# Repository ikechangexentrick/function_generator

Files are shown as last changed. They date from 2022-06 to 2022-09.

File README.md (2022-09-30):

# function_generator
8 channel clock processor/low frequency oscillator

front view

### [Schematic](https://raw.githubusercontent.com/ikechangexentrick/function_generator/master/hw/function_generator_v1_schematic.pdf)

## Prerequisites

### Hardware
- Raspberry Pi Pico
- SSD1306 based OLED display
  - I use [0.96in 128x64 OLED display](https://akizukidenshi.com/catalog/g/gP-12031/)
- MCP4922 Digital-to-Analog converter

### Software (Arduino libraries)
- [Display_OLED](https://github.com/ikechangexentrick/Display_OLED)
  - (required libraries also)
- [AD_DA_Converters](https://github.com/ikechangexentrick/AD_DA_Converters)

## Build instruction

... to be written ...

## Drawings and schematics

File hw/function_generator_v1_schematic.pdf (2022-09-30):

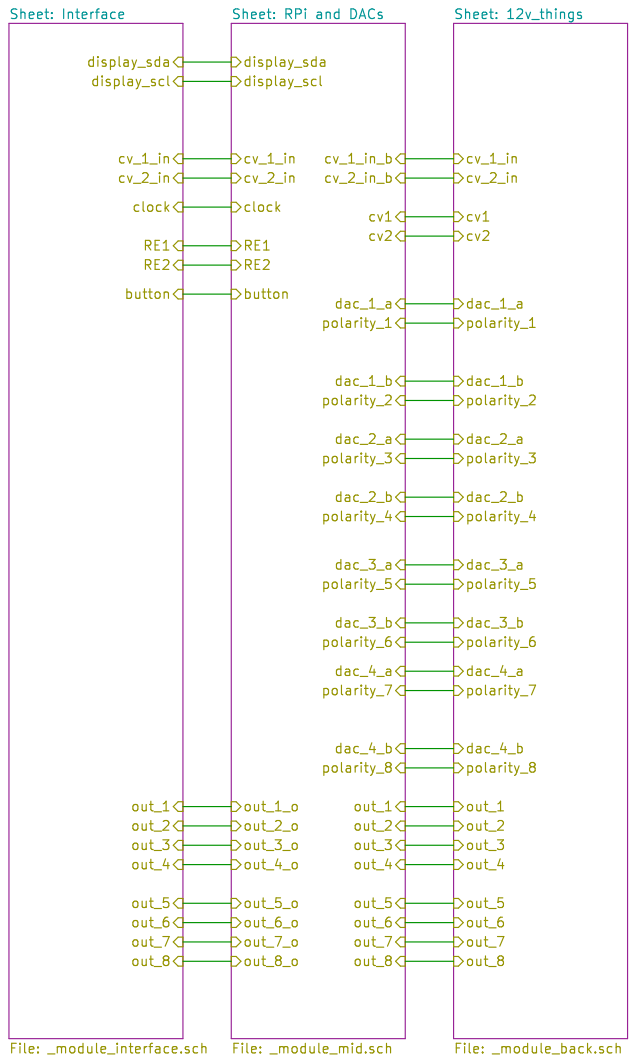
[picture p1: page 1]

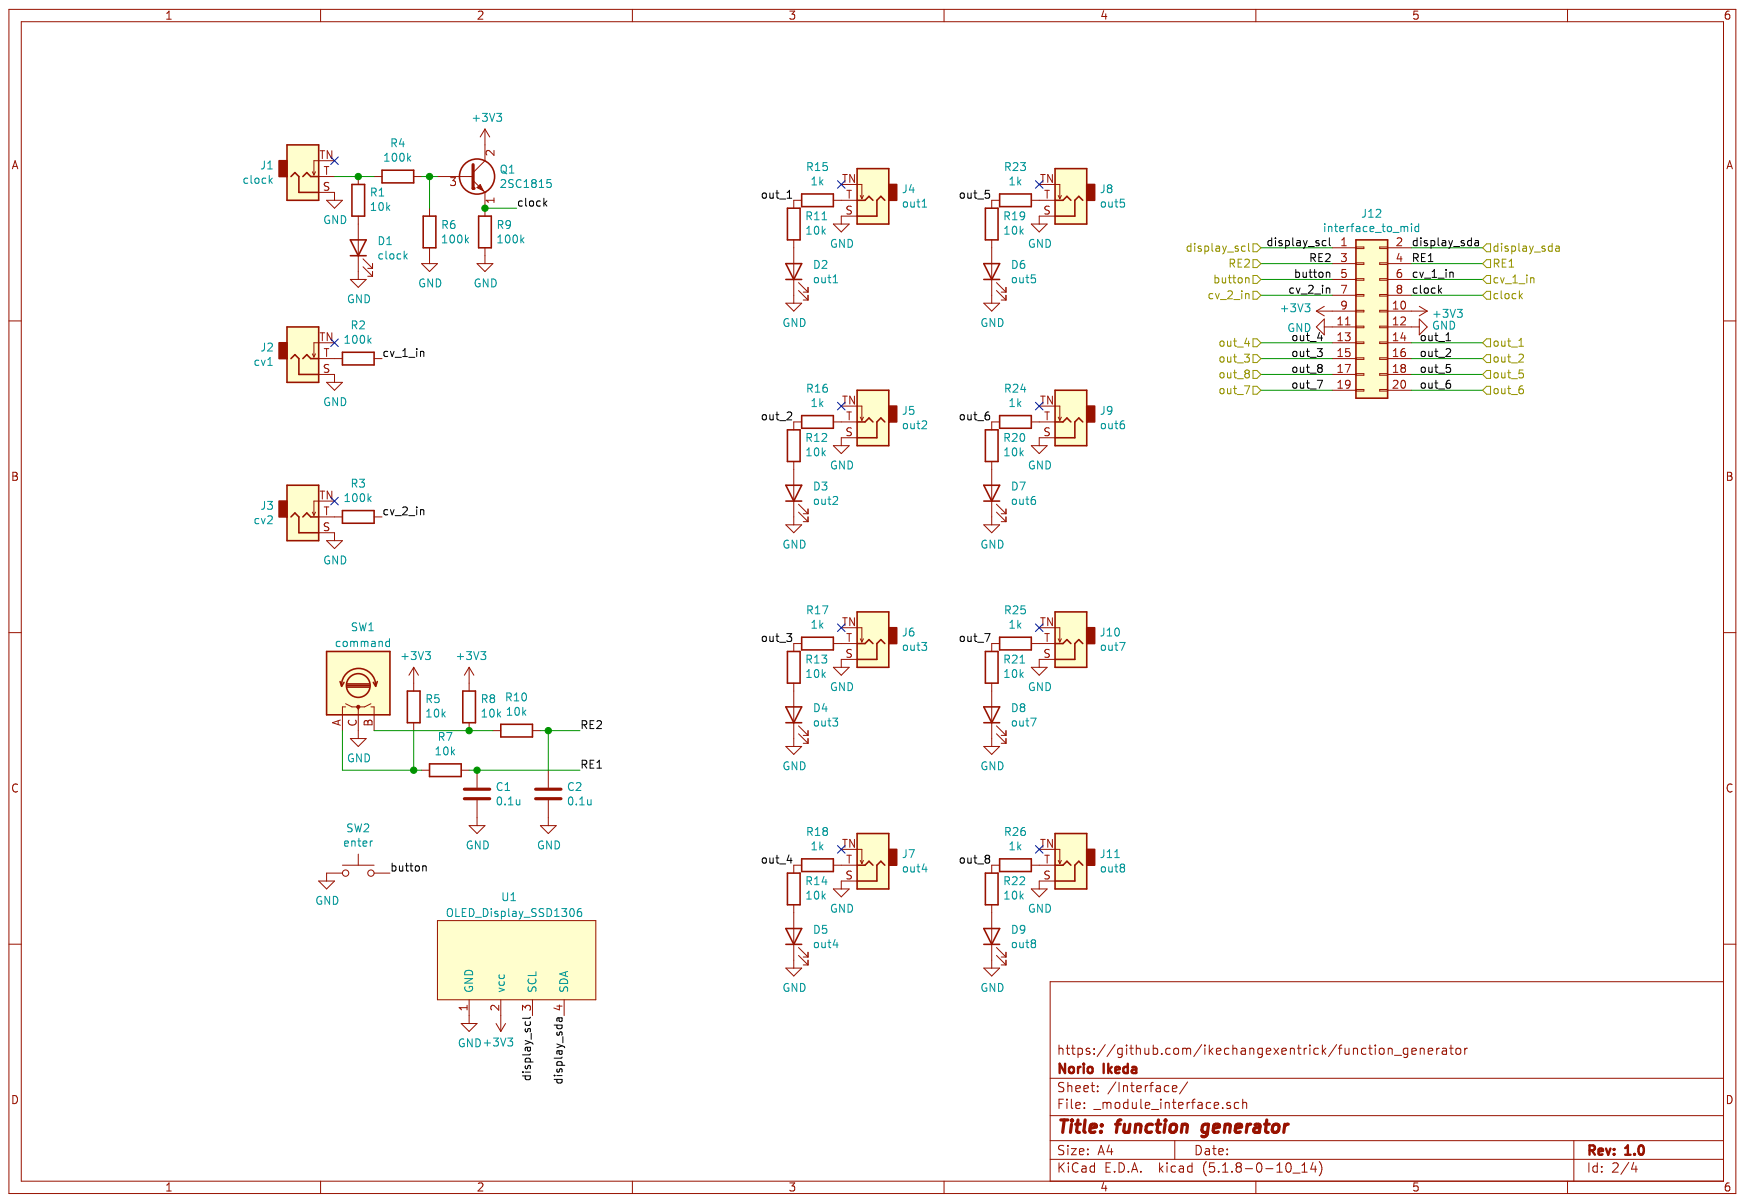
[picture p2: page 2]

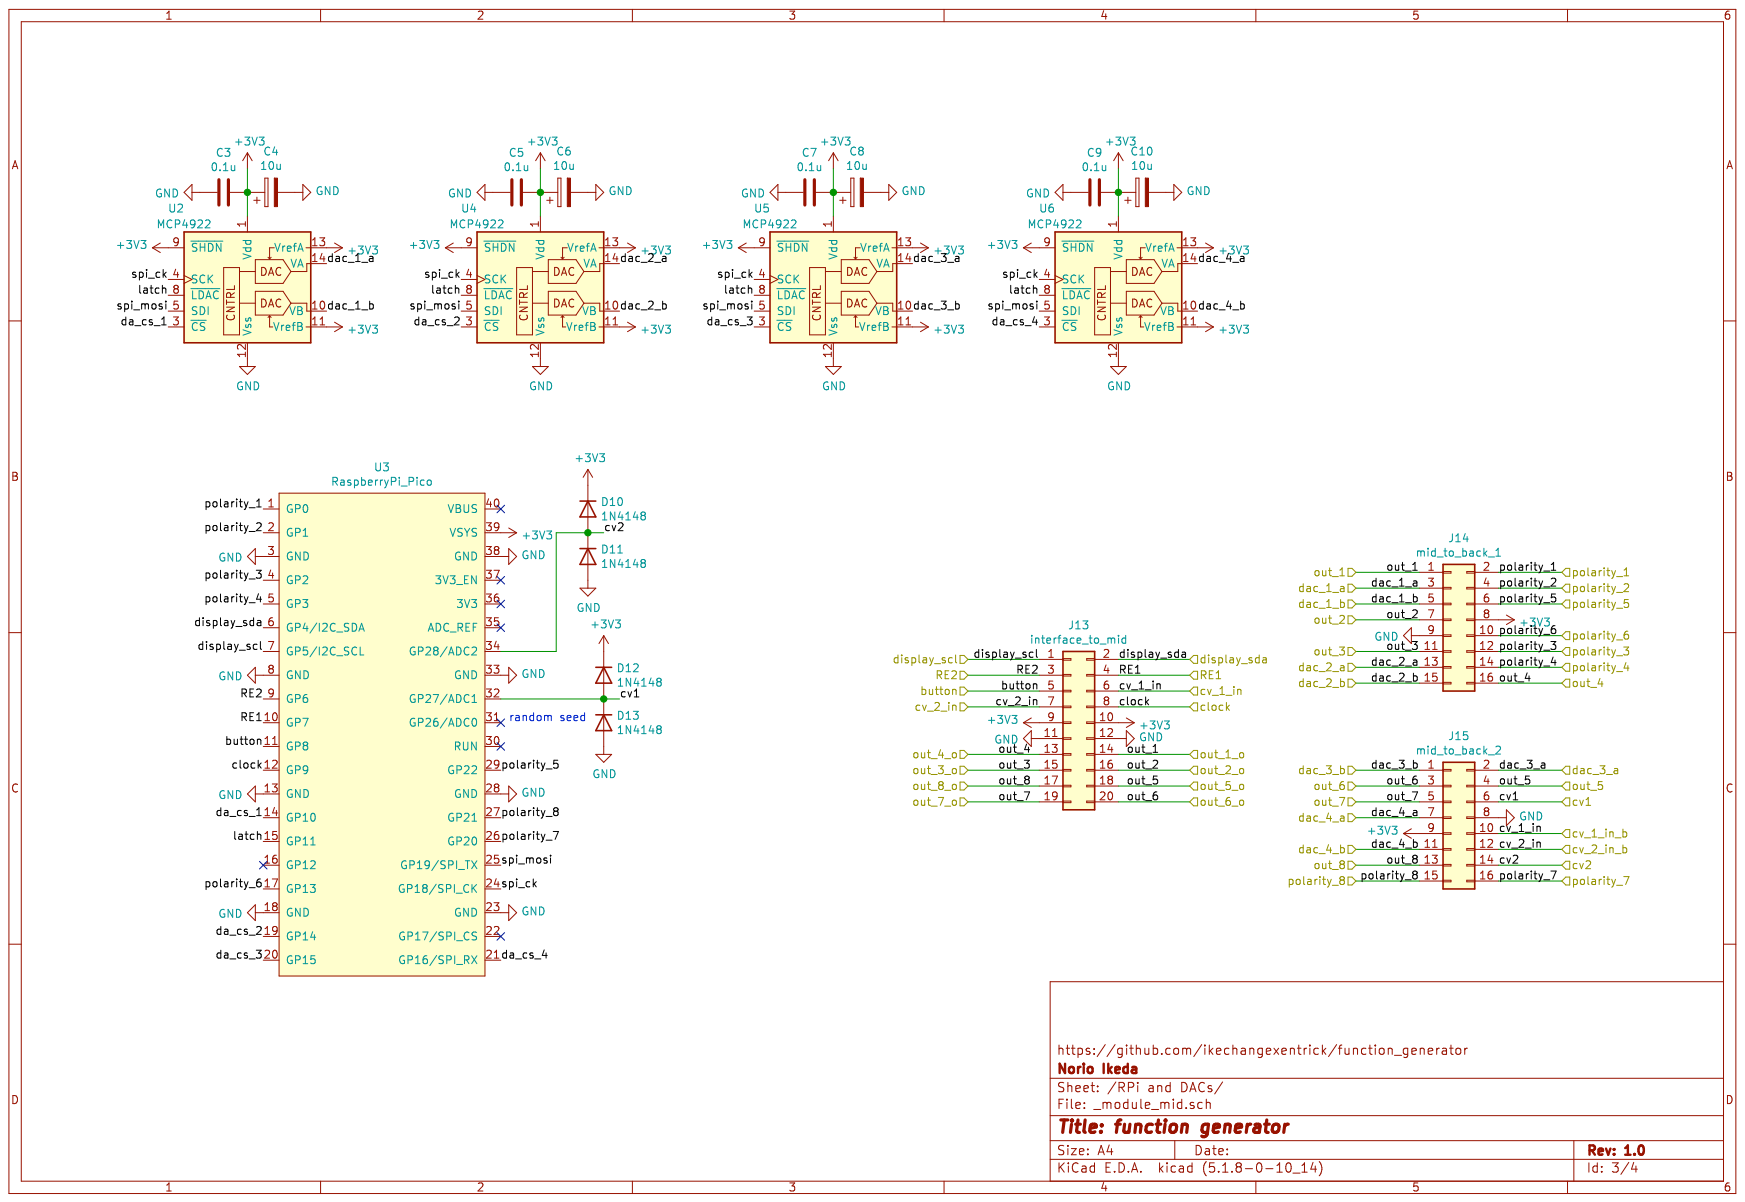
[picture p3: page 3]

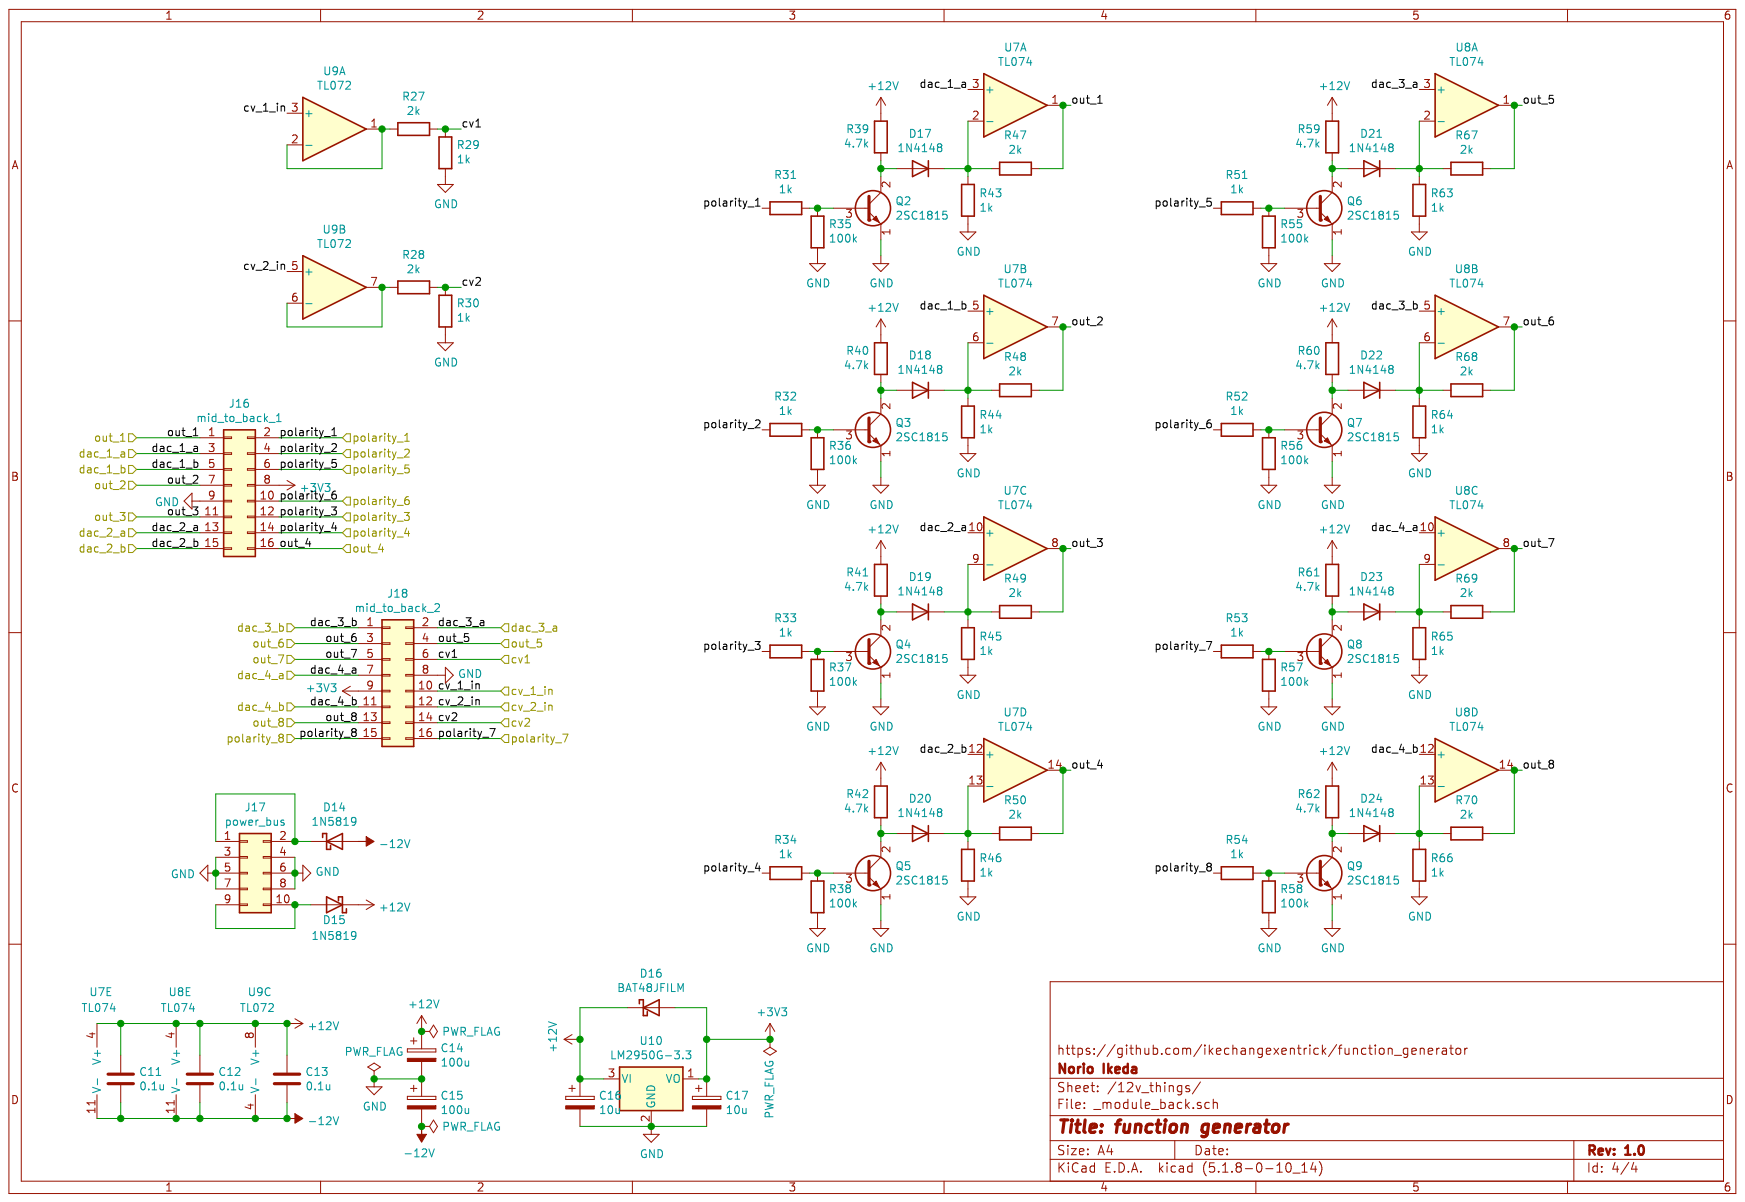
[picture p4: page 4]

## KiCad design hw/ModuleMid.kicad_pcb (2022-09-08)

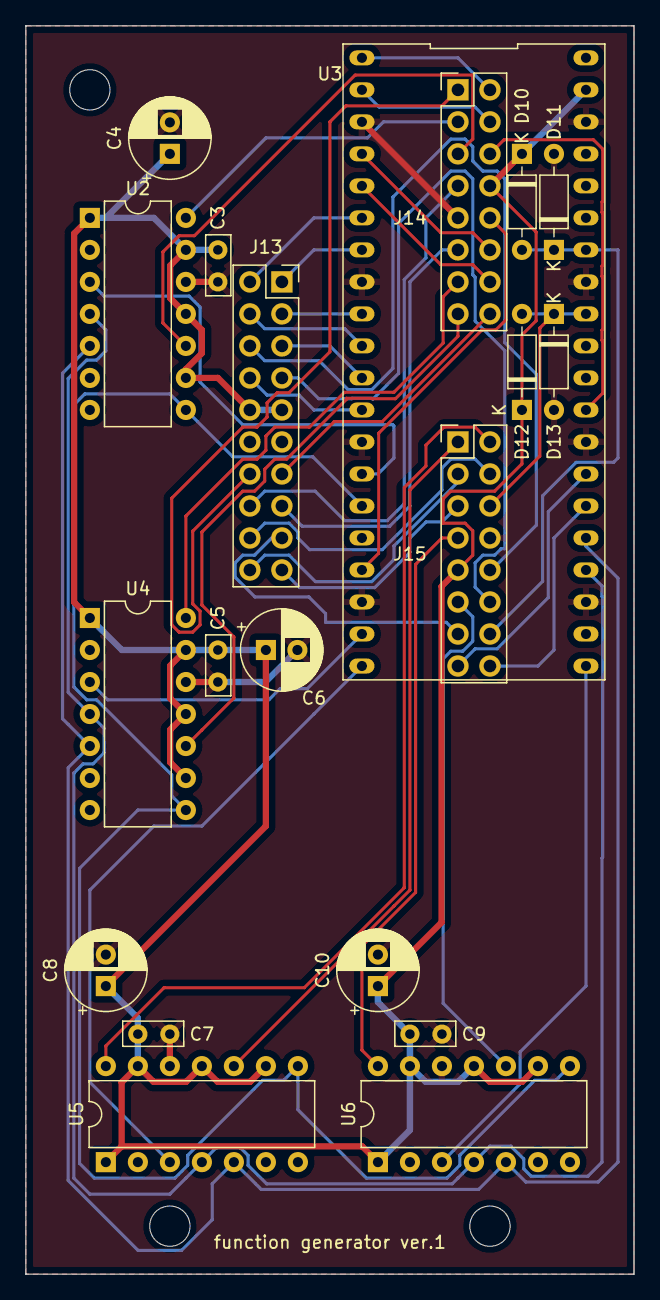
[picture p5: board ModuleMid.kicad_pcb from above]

Board: 2 copper layers, 48.3 x 99.1 mm, 20 parts (0 on the bottom side), 43 nets.

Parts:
C3, C5, C7, C9: 0.1u; C_Axial_L4.8mm_D2.0mm_P2.54mm_Horizontal
C4, C6, C8, C10: 10u; CP_Radial_D6.3mm_P2.50mm
D10, D11, D12, D13: 1N4148; D_DO-35_SOD27_P7.62mm_Horizontal
J13: interface_to_mid; PinSocket_2x10_P2.54mm_Vertical
J14: mid_to_back_1; PinHeader_2x08_P2.54mm_Vertical
J15: mid_to_back_2; PinHeader_2x08_P2.54mm_Vertical
U2, U4, U5, U6: MCP4922; DIP-14_W7.62mm
U3: RaspberryPi_Pico; Raspberry_Pi_pico_topside_up

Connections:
+3V3: C3.1, C4.1, C5.1, C6.1, C7.1, C8.1, C9.1, C10.1, D10.1, D12.1, J13.9, J13.10, J14.8, J15.9, U2.1, U2.9, U2.11, U2.13, U3.39, U4.1, U4.9, U4.11, U4.13, U5.1, U5.9, U5.11, U5.13, U6.1, U6.9, U6.11, U6.13
/RPi and DACs/RE1: J13.4, U3.10
/RPi and DACs/RE2: J13.3, U3.9
/RPi and DACs/button: J13.5, U3.11
/RPi and DACs/clock: J13.8, U3.12
/RPi and DACs/cv1: D12.2, D13.1, J15.6, U3.32
/RPi and DACs/cv2: D10.2, D11.1, J15.14, U3.34
/RPi and DACs/cv_1_in: J13.6, J15.10
/RPi and DACs/cv_2_in: J13.7, J15.12
/RPi and DACs/da_cs_1: U2.3, U3.14
/RPi and DACs/da_cs_2: U3.19, U4.3
/RPi and DACs/da_cs_3: U3.20, U5.3
/RPi and DACs/da_cs_4: U3.21, U6.3
/RPi and DACs/dac_1_a: J14.3, U2.14
/RPi and DACs/dac_1_b: J14.5, U2.10
/RPi and DACs/dac_2_a: J14.13, U4.14
/RPi and DACs/dac_2_b: J14.15, U4.10
/RPi and DACs/dac_3_a: J15.2, U5.14
/RPi and DACs/dac_3_b: J15.1, U5.10
/RPi and DACs/dac_4_a: J15.7, U6.14
/RPi and DACs/dac_4_b: J15.11, U6.10
/RPi and DACs/display_scl: J13.1, U3.7
/RPi and DACs/display_sda: J13.2, U3.6
/RPi and DACs/latch: U2.8, U3.15, U4.8, U5.8, U6.8
/RPi and DACs/out_1: J13.14, J14.1
/RPi and DACs/out_2: J13.16, J14.7
/RPi and DACs/out_3: J13.15, J14.11
/RPi and DACs/out_4: J13.13, J14.16
/RPi and DACs/out_5: J13.18, J15.4
/RPi and DACs/out_6: J13.20, J15.3
/RPi and DACs/out_7: J13.19, J15.5
/RPi and DACs/out_8: J13.17, J15.13
/RPi and DACs/polarity_1: J14.2, U3.1
/RPi and DACs/polarity_2: J14.4, U3.2
/RPi and DACs/polarity_3: J14.12, U3.4
/RPi and DACs/polarity_4: J14.14, U3.5
/RPi and DACs/polarity_5: J14.6, U3.29
/RPi and DACs/polarity_6: J14.10, U3.17
/RPi and DACs/polarity_7: J15.16, U3.26
/RPi and DACs/polarity_8: J15.15, U3.27
/RPi and DACs/spi_ck: U2.4, U3.24, U4.4, U5.4, U6.4
/RPi and DACs/spi_mosi: U2.5, U3.25, U4.5, U5.5, U6.5
GND: C3.2, C4.2, C5.2, C6.2, C7.2, C8.2, C9.2, C10.2, D11.2, D13.2, J13.11, J13.12, J14.9, J15.8, U2.12, U3.3, U3.8, U3.13, U3.18, U3.23, U3.28, U3.33, U3.38, U4.12, U5.12, U6.12

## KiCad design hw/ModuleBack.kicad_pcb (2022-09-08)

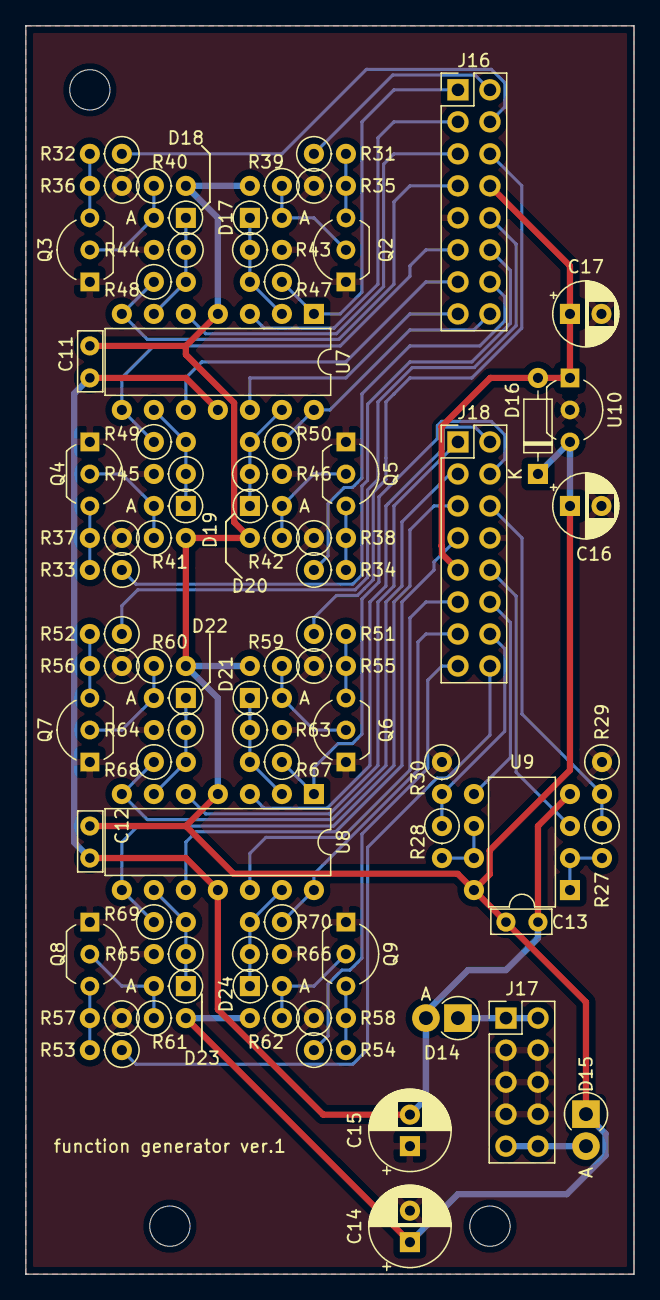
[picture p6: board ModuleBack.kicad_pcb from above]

Board: 2 copper layers, 48.3 x 99.1 mm, 77 parts (0 on the bottom side), 60 nets.

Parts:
C11, C12, C13: 0.1u; C_Axial_L4.8mm_D2.0mm_P2.54mm_Horizontal
C14, C15: 100u; CP_Radial_D6.3mm_P2.50mm
C16, C17: 10u; CP_Radial_D5.0mm_P2.50mm
D14, D15: 1N5819; D_DO-41_SOD81_P2.54mm_Vertical_AnodeUp
D16: BAT48JFILM; D_DO-35_SOD27_P7.62mm_Horizontal
D17, D18, D19, D20, D21, D22, D23, D24: 1N4148; D_DO-35_SOD27_P2.54mm_Vertical_AnodeUp
J16: mid_to_back_1; PinHeader_2x08_P2.54mm_Vertical
J17: power_bus; PinHeader_2x05_P2.54mm_Vertical
J18: mid_to_back_2; PinHeader_2x08_P2.54mm_Vertical
Q2, Q3, Q4, Q5, Q6, Q7, Q8, Q9: 2SC1815; TO-92_Inline_Wide
R27, R28, R47, R48, R49, R50, R67, R68, R69, R70: 2k; R_Axial_DIN0207_L6.3mm_D2.5mm_P2.54mm_Vertical
R29, R30, R31, R32, R33, R34, R43, R44, R45, R46, R51, R52, R53, R54, R63, R64, R65, R66: 1k; R_Axial_DIN0207_L6.3mm_D2.5mm_P2.54mm_Vertical
R35, R36, R37, R38, R55, R56, R57, R58: 100k; R_Axial_DIN0207_L6.3mm_D2.5mm_P2.54mm_Vertical
R39, R40, R41, R42, R59, R60, R61, R62: 4.7k; R_Axial_DIN0207_L6.3mm_D2.5mm_P2.54mm_Vertical
U7, U8: TL074; DIP-14_W7.62mm
U9: TL072; DIP-8_W7.62mm
U10: LM2950G-3.3; TO-92_Inline_Wide

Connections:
+3V3: C17.1, D16.2, J16.8, J18.9, U10.1
+12V: C11.1, C12.1, C13.1, C14.1, C16.1, D15.1, D16.1, R39.2, R40.2, R41.2, R42.2, R59.2, R60.2, R61.2, R62.2, U7.4, U8.4, U9.8, U10.3
-12V: C11.2, C12.2, C13.2, C15.2, D14.2, U7.11, U8.11, U9.4
/12v_things/cv1: J18.6, R27.1, R29.2
/12v_things/cv2: J18.14, R28.1, R30.2
/12v_things/cv_1_in: J18.10, U9.3
/12v_things/cv_2_in: J18.12, U9.5
/12v_things/dac_1_a: J16.3, U7.3
/12v_things/dac_1_b: J16.5, U7.5
/12v_things/dac_2_a: J16.13, U7.10
/12v_things/dac_2_b: J16.15, U7.12
/12v_things/dac_3_a: J18.2, U8.3
/12v_things/dac_3_b: J18.1, U8.5
/12v_things/dac_4_a: J18.7, U8.10
/12v_things/dac_4_b: J18.11, U8.12
/12v_things/out_1: J16.1, R47.1, U7.1
/12v_things/out_2: J16.7, R48.1, U7.7
/12v_things/out_3: J16.11, R49.1, U7.8
/12v_things/out_4: J16.16, R50.1, U7.14
/12v_things/out_5: J18.4, R67.1, U8.1
/12v_things/out_6: J18.3, R68.1, U8.7
/12v_things/out_7: J18.5, R69.1, U8.8
/12v_things/out_8: J18.13, R70.1, U8.14
/12v_things/polarity_1: J16.2, R31.1
/12v_things/polarity_2: J16.4, R32.1
/12v_things/polarity_3: J16.12, R33.1
/12v_things/polarity_4: J16.14, R34.1
/12v_things/polarity_5: J16.6, R51.1
/12v_things/polarity_6: J16.10, R52.1
/12v_things/polarity_7: J18.16, R53.1
/12v_things/polarity_8: J18.15, R54.1
GND: C14.2, C15.1, C16.2, C17.2, J16.9, J17.3, J17.4, J17.5, J17.6, J17.7, J17.8, J18.8, Q2.1, Q3.1, Q4.1, Q5.1, Q6.1, Q7.1, Q8.1, Q9.1, R29.1, R30.1, R35.1, R36.1, R37.1, R38.1, R43.2, R44.2, R45.2, R46.2, R55.1, R56.1, R57.1, R58.1, R63.2, R64.2, R65.2, R66.2, U10.2
unnamed: D14.1, J17.1, J17.2
unnamed: D15.2, J17.9, J17.10
unnamed: D17.1, R43.1, R47.2, U7.2
unnamed: D17.2, Q2.2, R39.1
unnamed: D18.1, R44.1, R48.2, U7.6
unnamed: D18.2, Q3.2, R40.1
unnamed: D19.1, R45.1, R49.2, U7.9
unnamed: D19.2, Q4.2, R41.1
unnamed: D20.1, R46.1, R50.2, U7.13
unnamed: D20.2, Q5.2, R42.1
unnamed: D21.1, R63.1, R67.2, U8.2
unnamed: D21.2, Q6.2, R59.1
unnamed: D22.1, R64.1, R68.2, U8.6
unnamed: D22.2, Q7.2, R60.1
unnamed: D23.1, R65.1, R69.2, U8.9
unnamed: D23.2, Q8.2, R61.1
unnamed: D24.1, R66.1, R70.2, U8.13
unnamed: D24.2, Q9.2, R62.1
unnamed: Q2.3, R31.2, R35.2
unnamed: Q3.3, R32.2, R36.2
unnamed: Q4.3, R33.2, R37.2
unnamed: Q5.3, R34.2, R38.2
unnamed: Q6.3, R51.2, R55.2
unnamed: Q7.3, R52.2, R56.2
unnamed: Q8.3, R53.2, R57.2
unnamed: Q9.3, R54.2, R58.2
unnamed: R27.2, U9.1, U9.2
unnamed: R28.2, U9.6, U9.7

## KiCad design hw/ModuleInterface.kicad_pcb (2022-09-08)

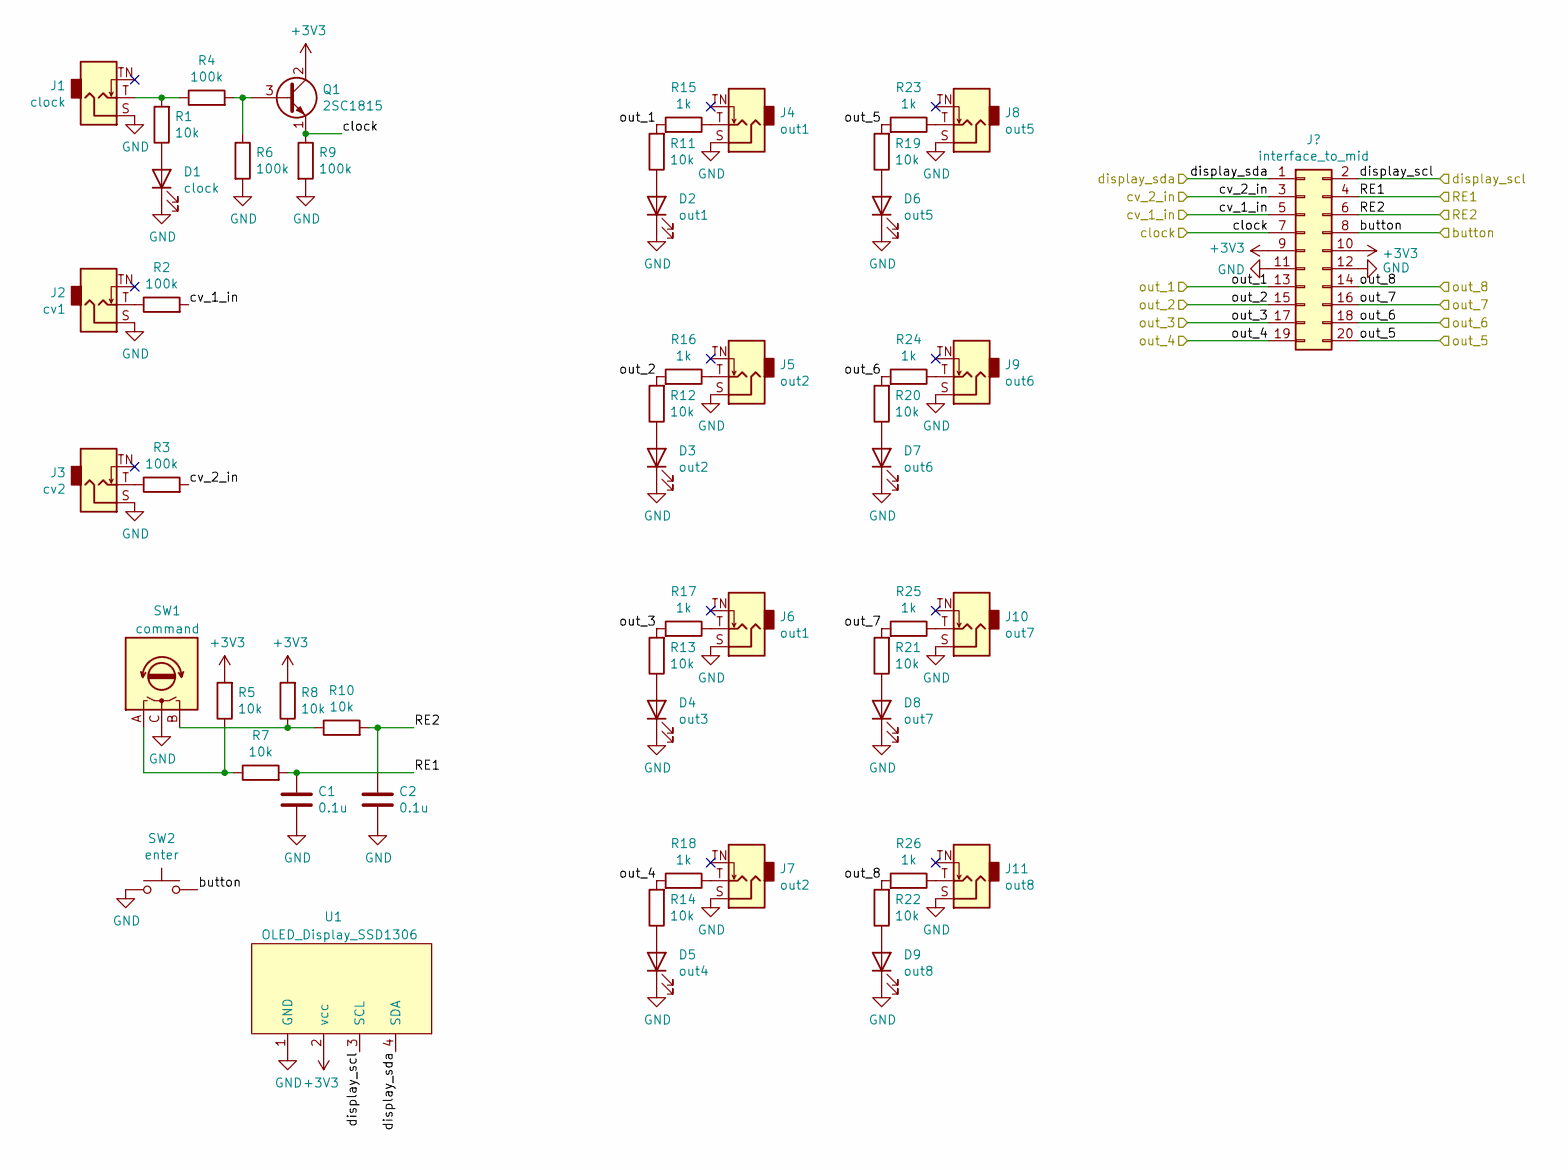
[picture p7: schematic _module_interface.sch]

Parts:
C1, C2: 0.1u
D1: clock
D2: out1
D3: out2
D4: out3
D5: out4
D6: out5
D7: out6
D8: out7
D9: out8
J1: clock
J2: cv1
J3: cv2
J4, J6: out1
J5, J7: out2
J8: out5
J9: out6
J10: out7
J11: out8
Q1: 2SC1815; TO-92_Inline
R1, R5, R7, R8, R10, R11, R12, R13, R14, R19, R20, R21, R22: 10k
R2, R3, R4, R6, R9: 100k
R15, R16, R17, R18, R23, R24, R25, R26: 1k
SW1: command
SW2: enter
U1: OLED_Display_SSD1306

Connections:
+3V3: Q1.2 (C), R5.2, R8.2, U1.2 (vcc); also elsewhere on the board
/Interface/RE1: C1.1, R7.2; also elsewhere on the board
/Interface/RE2: C2.1, R10.2; also elsewhere on the board
/Interface/button: SW2.2; also elsewhere on the board
/Interface/clock: Q1.1 (E), R9.1; also elsewhere on the board
/Interface/cv_1_in: R2.2; also elsewhere on the board
/Interface/cv_2_in: R3.2; also elsewhere on the board
/Interface/display_scl: U1.3 (SCL); also elsewhere on the board
/Interface/display_sda: U1.4 (SDA); also elsewhere on the board
/Interface/out_1: R11.2, R15.2; also elsewhere on the board
/Interface/out_2: R12.2, R16.2; also elsewhere on the board
/Interface/out_3: R13.2, R17.2; also elsewhere on the board
/Interface/out_4: R14.2, R18.2; also elsewhere on the board
/Interface/out_5: R19.2, R23.2; also elsewhere on the board
/Interface/out_6: R20.2, R24.2; also elsewhere on the board
/Interface/out_7: R21.2, R25.2; also elsewhere on the board
/Interface/out_8: R22.2, R26.2; also elsewhere on the board
GND: C1.2, C2.2, D1.1 (K), D2.1 (K), D3.1 (K), D4.1 (K), D5.1 (K), D6.1 (K), D7.1 (K), D8.1 (K), D9.1 (K), J1.S, J2.S, J3.S, J4.S, J5.S, J6.S, J7.S, J8.S, J9.S, J10.S, J11.S, R6.2, R9.2, SW1.C, SW2.1, U1.1 (GND); also elsewhere on the board
unnamed: D1.2 (A), R1.1
unnamed: D2.2 (A), R11.1
unnamed: D3.2 (A), R12.1
unnamed: D4.2 (A), R13.1
unnamed: D5.2 (A), R14.1
unnamed: D6.2 (A), R19.1
unnamed: D7.2 (A), R20.1
unnamed: D8.2 (A), R21.1
unnamed: D9.2 (A), R22.1
unnamed: J1.T, R1.2, R4.1
unnamed: J2.T, R2.1
unnamed: J3.T, R3.1
unnamed: J4.T, R15.1
unnamed: J5.T, R16.1
unnamed: J6.T, R17.1
unnamed: J7.T, R18.1
unnamed: J8.T, R23.1
unnamed: J9.T, R24.1
unnamed: J10.T, R25.1
unnamed: J11.T, R26.1
unnamed: Q1.3 (B), R4.2, R6.1
unnamed: R5.1, R7.1, SW1.A
unnamed: R8.1, R10.1, SW1.B

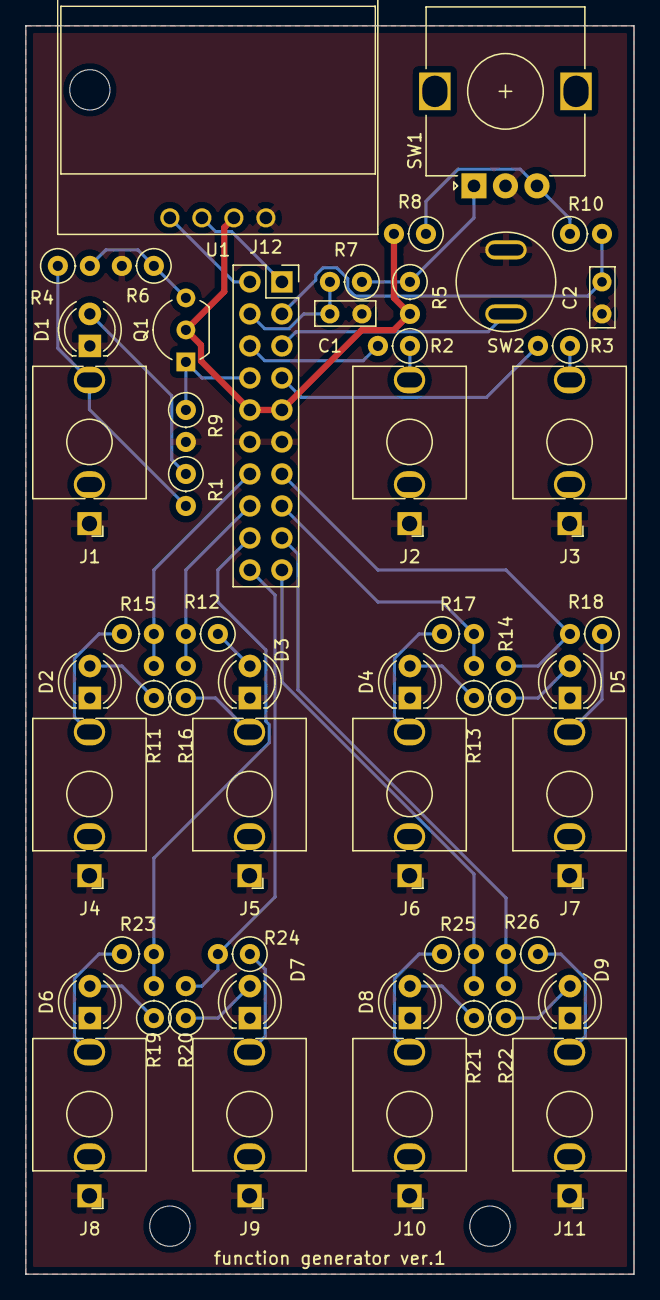
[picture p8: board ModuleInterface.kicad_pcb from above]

Board: 2 copper layers, 48.3 x 99.1 mm, 53 parts (0 on the bottom side), 41 nets.

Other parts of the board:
J12: interface_to_mid; PinSocket_2x10_P2.54mm_Vertical

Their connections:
+3V3: J12.9, J12.10; also elsewhere on the board
/Interface/RE1: J12.4; also elsewhere on the board
/Interface/RE2: J12.3; also elsewhere on the board
/Interface/button: J12.5; also elsewhere on the board
/Interface/clock: J12.8; also elsewhere on the board
/Interface/cv_1_in: J12.6; also elsewhere on the board
/Interface/cv_2_in: J12.7; also elsewhere on the board
/Interface/display_scl: J12.1; also elsewhere on the board
/Interface/display_sda: J12.2; also elsewhere on the board
/Interface/out_1: J12.14; also elsewhere on the board
/Interface/out_2: J12.16; also elsewhere on the board
/Interface/out_3: J12.15; also elsewhere on the board
/Interface/out_4: J12.13; also elsewhere on the board
/Interface/out_5: J12.18; also elsewhere on the board
/Interface/out_6: J12.20; also elsewhere on the board
/Interface/out_7: J12.19; also elsewhere on the board
/Interface/out_8: J12.17; also elsewhere on the board
GND: J12.11, J12.12; also elsewhere on the board

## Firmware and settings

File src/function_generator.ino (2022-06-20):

#include <SPI.h>
#include "function_generator_ui.h"
#include "button.h"
#include "Display_OLED.h"
#include "AD_DA_Converters.h"

#include "ArxTypeTraits.h"

static const int SERIAL_BAUD_RATE = 9600;

static const size_t BUFLEN = 64;
char msg_buf[BUFLEN];

template <typename... Args>
void serial_log(const char *fmt, Args... args)
{
	snprintf(msg_buf, BUFLEN, fmt, args...);
	Serial.println( msg_buf );
}

//  -----------------------------------------------

SPISettings settings(1000000, MSBFIRST, SPI_MODE0);

//  -----------------------------------------------

static const int PIN_RANDOM_SEED = 26; // ADC0

/*
static const double V_REF = 5.0;
*/

const int PIN_DA_CS = 10;
const int PIN_DA_CS_2 = 14;
const int PIN_DA_CS_3 = 15;
const int PIN_DA_CS_4 = 16;

const int PIN_DA_LATCH = 11;

static const int PIN_ROTARY_SW1 = 7;
static const int PIN_ROTARY_SW2 = 6;
static const int PIN_BUTTON = 8;
static const int PIN_CLOCK = 9;

static const int PIN_CV1 = 27; // ADC1
static const int PIN_CV2 = 28; // ADC2


//  -----------------------------------------------

Display_OLED display;

//  -----------------------------------------------

MCP4922 dac1(settings, PIN_DA_CS, PIN_DA_LATCH);
MCP4922 dac2(settings, PIN_DA_CS_2, PIN_DA_LATCH);
MCP4922 dac3(settings, PIN_DA_CS_3, PIN_DA_LATCH);
MCP4922 dac4(settings, PIN_DA_CS_4, PIN_DA_LATCH);

//  -----------------------------------------------

/*
Channel> app_channel
Free>
  Frequency> app_freq
	<Back
Synchronize>
	Source> app_src
  Multiply> app_mult
  Phase> app_phase
	<Back
Function>
	[sin]
	[saw]
	[tri]
	[sq]
	AR envelope>
		Attack> app_are_attack
		Release> app_are_release
		<Back
	<Back
Pattern>
	[Off]
	Euclidean>
		Length> app_euc_len
		Number> app_euc_num
		Shift> app_euc_sft
		<Back
	<Back
Polarity> app_polarity (not implemented yet)
CV1>
	Channel> app_cv1_channel (ChannelApp)
	Function> app_cv1
		[Off]
		[Freq]
		[Multiplicity]
		[Phase]
		[Function]
		[Attack]
		[Release]
		[Euclidean_len]
		[Euclidean_num]
		[Euclidean_sft]
CV2> app_cv2
	Channel> app_cv2_channel
	Function> app_cv2
*/

//  -----------------------------------------------

void show_cvconfig(const CVConfig &cfg)
{
	serial_log("----");
	serial_log("channel: %d", cfg.ch);
	serial_log("freq: %d", cfg.freq);
	serial_log("Mult: %d Phase: %d", cfg.mult, cfg.phase);
	serial_log("Func: %d Attack: %d Release: %d", cfg.func, cfg.are_attack, cfg.are_release);
	serial_log("Len: %d Num: %d Shift: %d", cfg.euc_len, cfg.euc_num, cfg.euc_sft);
}

Menu_Channel menu_channel;

Menu_Free menu_free;
Menu_Freq menu_freq;

Menu_Sync menu_sync;
Menu_Src menu_src;
Menu_Mult menu_mult;
Menu_Phase menu_phase;

MenuApp app_menu(&menu_channel, &display);

Menu_Back menu_free_back("<Back", &app_menu);
Menu_Back menu_sync_back("<Back", &app_menu);

Menu_Func menu_func;
Menu_Func_sin menu_func_sin;
Menu_Func_saw menu_func_saw;
Menu_Func_tri menu_func_tri;
Menu_Func_sq menu_func_sq;
Menu_Func_ARE menu_func_are;
Menu_Func_ARE_Attack menu_func_are_attack;
Menu_Func_ARE_Release menu_func_are_release;
Menu_Back menu_func_are_back("<Back", &app_menu);
Menu_Back menu_func_back("<Back", &app_menu);

Menu_Pattern menu_ptn;
Menu_Pattern_Off menu_ptn_off;
Menu_Pattern_Euclidean menu_ptn_euc;
Menu_Back menu_ptn_back("<Back", &app_menu);

Menu_Pattern_Euclidean_Length menu_ptn_euc_len;
Menu_Pattern_Euclidean_Number menu_ptn_euc_num;
Menu_Pattern_Euclidean_Shift menu_ptn_euc_sft;
Menu_Back menu_ptn_euc_back("<Back", &app_menu);

// ---------

template <int N, typename Head, typename... Tail>
struct Take
{
	static_assert(N > 1, "N must be equal to or larger than 1.");
	using type = typename Take<N-1, Tail...>::type;
};

template <typename Head, typename... Tail>
struct Take<1, Head, Tail...>
{
	using type = typename std::tuple<Tail...>;
};

template <int M, int N, typename... T>
struct Cdrer
{
	static typename Take<M-N, T...>::type get(const std::tuple<T...> &t) {
		return std::tuple_cat( std::make_tuple(std::get<M-N>(t)),  Cdrer<M, N-1, T...>::get(t) );
	}
};

template <int M, typename... T>
struct Cdrer<M, 1, T...>
{
	static typename Take<M-1, T...>::type get(const std::tuple<T...> &t) {
		return std::make_tuple(std::get<M-1>(t));
	}
};


template <typename Head, typename... Rest>
std::tuple<Rest...> cdr(const std::tuple<Head, Rest...> &t) {
	return Cdrer<sizeof...(Rest)+1, sizeof...(Rest), Head, Rest...>::get(t);
}

template <typename Head, typename... Tail>
void unset(CVConfig *p, const std::tuple<Head, Tail...> &args)
{
	auto &head = std::get<0>(args);
	p->*head = false;
	unset(p, cdr(args));
}

template <typename Head>
void unset(CVConfig *p, const std::tuple<Head> &args)
{
	auto &head = std::get<0>(args);
	p->*head = false;
}

template <typename... Rest>
void exclusive_set(CVConfig *p, bool CVConfig::*memp, const std::tuple<Rest...> &args)
{
	unset(p, args);
	p->*memp = true;
}

// ---------

auto gp = std::make_tuple(
	&CVConfig::euc_len
	, &CVConfig::freq, &CVConfig::mult, &CVConfig::are_attack, &CVConfig::euc_num
	, &CVConfig::func, &CVConfig::phase, &CVConfig::are_release, &CVConfig::euc_sft
);

auto set_gp = [](CVConfig *p, bool CVConfig::*memp) { exclusive_set(p, memp, gp); };

constexpr const size_t CV_NUM = 2;
CVConfig cvc[CV_NUM];

#define CreateAppCv(name, ch) \
CVApp<10> name( \
	{"Off" \
		, "Frequency" \
		, "Multiplicity" \
		, "Phase" \
		, "Function" \
		, "Attack" \
		, "Release" \
		, "Euclidean_len" \
		, "Euclidean_num" \
		, "Euclidean_sft" \
	}, \
	{ \
		[](){unset(&cvc[ch], gp);} \
		, [](){set_gp(&cvc[ch], &CVConfig::freq);} \
		, [](){set_gp(&cvc[ch], &CVConfig::mult);} \
		, [](){set_gp(&cvc[ch], &CVConfig::phase);} \
		, [](){set_gp(&cvc[ch], &CVConfig::func);} \
		, [](){set_gp(&cvc[ch], &CVConfig::are_attack);} \
		, [](){set_gp(&cvc[ch], &CVConfig::are_release);} \
		, [](){set_gp(&cvc[ch], &CVConfig::euc_len);} \
		, [](){set_gp(&cvc[ch], &CVConfig::euc_num);} \
		, [](){set_gp(&cvc[ch], &CVConfig::euc_sft);} \
});

CreateAppCv(app_cv1, 0);
CreateAppCv(app_cv2, 1);

Menu_CV_Base menu_cv1_base("CV1>");
Menu_CV_Base menu_cv2_base("CV2>");

ChannelApp app_cv1_channel;
ChannelApp app_cv2_channel;
ChannelApp *app_cv_c[CV_NUM] = {
	&app_cv1_channel, &app_cv2_channel
};

Menu_CV_Channel menu_cv1_channel(app_cv_c[0]);
Menu_CV_Channel menu_cv2_channel(app_cv_c[1]);

Menu_CV menu_cv1("Function>", &app_cv1);
Menu_CV menu_cv2("Function>", &app_cv2);

Menu_Back menu_cv1_back("<Back", &app_menu);
Menu_Back menu_cv2_back("<Back", &app_menu);

ChannelApp app_channel;
FreqApp app_freq;

SrcApp app_src;
MultApp app_mult;
PhaseApp app_phase;

FuncApp app_func;
ARE_Attack_App app_func_are_attack;
ARE_Release_App app_func_are_release;

PatternController ptnctl;
Euclid_Len_App app_euc_len;
Euclid_Num_App app_euc_num;
Euclid_Sft_App app_euc_sft;

Application *app = &app_menu;

//  -----------------------------------------------

class RSW_cmd : public RotarySwitch
{
public:
	RSW_cmd(int pin_1, int pin_2)
		: RotarySwitch(pin_1, pin_2)
	{}

private:
	virtual void onRotarySW(RSW_DIR dir) override
	{
		if (app) app->onRotarySW(dir);
	}
};

RSW_cmd rsw1(PIN_ROTARY_SW1, PIN_ROTARY_SW2);

//  -----------------------------------------------

class Button_func : public Button
{
public:
	Button_func(int pin)
		: Button(pin)
	{}

private:
	virtual void onButton(int state) override
	{
		if (app) app->onButton(state);
	}
};

Button_func button_1(PIN_BUTTON);

//  -----------------------------------------------

void onRotary() {
	rsw1.callback();
}

void onButton() {
	button_1.callback();
}

volatile unsigned long prev_clock = 0;

void onClock()
{
	if (digitalRead(PIN_CLOCK) == HIGH) {
		unsigned long cur = micros();
		auto period = cur - prev_clock;
		//display.show_app_msg("clock %5.1f Hz, %5.1f bpm", 1e6/(double)period, 60e6/(double)period);

		auto f = 1e6/(double)period; // freqeuncy of the clock
		auto p = cur % period; // phase of the clock
		//serial_log("%7d %7d %7.3f %d", cur, period, f, cur % period);

		// synchronize frequency and phase with external clock
		for (size_t ch = 0; ch < ChannelApp::ChannelMax; ++ch) {
			if (app_freq.sync_mode(ch) == FreqApp::Sync_ExtClock) {
				app_freq.set_param(ch, f, p);
			}
		}

		prev_clock = cur;
	}
}

//  -----------------------------------------------

void onPeriodStarts(size_t ch)
{
	// synchronize frequency and phase with selected channel
	auto f = app_freq.get_frequency(ch);
	auto p = app_freq.get_phase(ch);
	for (size_t s = 0; s < ChannelApp::ChannelMax; ++s) {
		if (app_freq.sync_mode(s) == (FreqApp::SyncType)ch) {
			app_freq.set_param(s, f, p);
		}
	}

	ptnctl.notify(ch);
}

//  -----------------------------------------------

volatile unsigned long prev = 0;
volatile unsigned int cnt = 0;
constexpr const size_t MEAN_WIDTH = 40;

#undef MEASUREMENT
#ifdef MEASUREMENT
volatile unsigned long buf[MEAN_WIDTH];
#endif // MEASUREMENT

static void emit(size_t ch, unsigned long cur)
{
	if (app_freq.check_new_period(ch, cur)) {
		onPeriodStarts(ch);
	}

	double out = 0;
	if (ptnctl.enabled(ch)) {
		auto func = app_func.get_function(ch);
		auto freq = app_freq.get_frequency(ch);
		auto p = app_freq.get_phase(ch);

		if (app_freq.sync_mode(ch) != FreqApp::Free) {
			auto coeff = app_mult.get_coeff(ch);
			auto factor = app_phase.get_factor(ch);
			out = func(cur, freq*coeff, p + 1e6/freq/8.0*factor);
		} else {
			out = func(cur, freq, p);
		}
	}

	MCP4922 *dac;
	if (ch < 2) dac = &dac1;
	else if (ch < 4) dac = &dac2;
	else if (ch < 6) dac = &dac3;
	else if (ch < 8) dac = &dac4;

	if (ch % 2 == 0) {
		dac->emit(out, Channel_A);
	} else {
		dac->emit(out, Channel_B);
	}
}

bool onTimer(repeating_timer_t *	)
{
	unsigned long cur = micros();

#ifdef MEASUREMENT
	auto delta_t = cur - prev;
	buf[cnt] = delta_t;
#endif // MEASUREMENT

	const auto ch = app_channel.get_current_channel();

	// calculate mean looping time of recent MEAN_WIDTH
	if (++cnt >= MEAN_WIDTH) {
#ifdef MEASUREMENT
		double sum = 0;
		for (int i = 0; i < MEAN_WIDTH; ++i) sum += buf[i];
		sum /= (double)MEAN_WIDTH;
#endif // MEASUREMENT

#ifdef MEASUREMENT
		display.show_status(
			"%3.0f us %5.1f Hz", sum, 1e6/sum
		);
#else // MEASUREMENT
		auto mode = app_freq.sync_mode(ch);
		if (mode != FreqApp::Free) {
			display.show_status(
				"%u:%s %s %s%d +%d", ch+1, app_func.get_func_name(ch)
				, get_source_name(mode)
				, app_mult.get_sign(ch), app_mult.get_factor(ch)
				, app_phase.get_factor(ch)
			);

		} else {
			const auto freq = app_freq.get_frequency(ch);
			display.show_status(
				"%u:%s %4.1fHz %3.0fbpm", ch+1, app_func.get_func_name(ch)
				, freq, freq*60
			);
		}
#endif // MEASUREMENT

		//serial_log("%d", analogRead(PIN_CV1));

		cnt = 0;
	}

	for (size_t ch = 0; ch < ChannelApp::ChannelMax; ++ch) {
		emit(ch, cur);
	}

	prev = cur;

	return true;
}

repeating_timer_t timer_data;

void setup() {
  Serial.begin(SERIAL_BAUD_RATE);

	randomSeed(analogRead(PIN_RANDOM_SEED));

	pinMode(PIN_DA_CS, OUTPUT);
	pinMode(PIN_DA_CS_2, OUTPUT);
	pinMode(PIN_DA_CS_3, OUTPUT);
	pinMode(PIN_DA_CS_4, OUTPUT);
	pinMode(PIN_DA_LATCH, OUTPUT);

	pinMode(PIN_ROTARY_SW1, INPUT);
	attachInterrupt(digitalPinToInterrupt(PIN_ROTARY_SW1), onRotary, CHANGE);
	pinMode(PIN_ROTARY_SW2, INPUT);

	pinMode(PIN_CLOCK, INPUT);
	attachInterrupt(digitalPinToInterrupt(PIN_CLOCK), onClock, CHANGE);

	pinMode(PIN_BUTTON, INPUT_PULLUP);
	attachInterrupt(digitalPinToInterrupt(PIN_BUTTON), onButton, CHANGE);

	menu_channel.add_sibling(&menu_free);
	menu_free.add_sibling(&menu_sync);
	menu_sync.add_sibling(&menu_func);
	menu_func.add_sibling(&menu_ptn);
	menu_ptn.add_sibling(&menu_cv1_base);
	menu_cv1_base.add_sibling(&menu_cv2_base);

	menu_free.add_child(&menu_freq);
	menu_freq.add_sibling(&menu_free_back); // add_sibling should follow add_child.

	menu_sync.add_child(&menu_src);
	menu_src.add_sibling(&menu_mult);
	menu_mult.add_sibling(&menu_phase); // add_sibling should follow add_child.
	menu_phase.add_sibling(&menu_sync_back); // add_sibling should follow add_child.

	menu_func.add_child(&menu_func_sin);
	menu_func_sin.add_sibling(&menu_func_saw);
	menu_func_saw.add_sibling(&menu_func_tri);
	menu_func_tri.add_sibling(&menu_func_sq);
	menu_func_sq.add_sibling(&menu_func_are);
	menu_func_are.add_sibling(&menu_func_back);

	menu_func_are.add_child(&menu_func_are_attack);
	menu_func_are_attack.add_sibling(&menu_func_are_release);
	menu_func_are_release.add_sibling(&menu_func_are_back);

	menu_ptn.add_child(&menu_ptn_off);
	menu_ptn_off.add_sibling(&menu_ptn_euc);
	menu_ptn_euc.add_sibling(&menu_ptn_back);

	menu_ptn_euc.add_child(&menu_ptn_euc_len);
	menu_ptn_euc_len.add_sibling(&menu_ptn_euc_num);
	menu_ptn_euc_num.add_sibling(&menu_ptn_euc_sft);
	menu_ptn_euc_sft.add_sibling(&menu_ptn_euc_back);

	menu_cv1_base.add_child(&menu_cv1_channel);
	menu_cv1_channel.add_sibling(&menu_cv1);
	menu_cv1.add_sibling(&menu_cv1_back);

	menu_cv2_base.add_child(&menu_cv2_channel);
	menu_cv2_channel.add_sibling(&menu_cv2);
	menu_cv2.add_sibling(&menu_cv2_back);

	SPI.begin();

	display.init();
	display.show_menu(app_menu.get_current()->get_title());

	add_repeating_timer_us(250, onTimer, 0, &timer_data);
}

void loop() {
	//display.test();

	// graphics functions cannot be called in interruption callbacks.
	display.display(
		[&](){
			display.show_menu();
		}
	);
}

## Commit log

2022-06-20 low-frequency function generator, on Raspberry Pi Pico.
2022-06-20 Multi channel support. Note that currently only 2 outputs are hard-coded.
2022-06-20 Master channel for synchronization can be selected via "Source" menu. Improved phase stability of synchronization. "onPeriodStarts" callback will be called when a period starts for each channel.
    [function_generator.ino]
2022-06-20 Updated menu structure; different representation for "switch" and "sub menu" types. Added AR (Attack-Release) envelope function. Added "Pattern" functionality; supports euclidean rhythm. Fixed a bug 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
    [function_generator.ino]
2022-06-20 Software: supports 8 channel output. supports CV control functionality.
    Hardware:
    appended kicad project files.
    [ModuleBack.sch, ModuleInterface.sch, ModuleMid.sch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]
2022-06-20 hardware: artwork done.
    [ModuleBack.kicad_pcb, ModuleInterface.kicad_pcb, ModuleMid.kicad_pcb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]
2022-06-20 Software: appended polarity selection functionality. Hardware: appended power reversal protection. adjusted silks.
    [ModuleBack.kicad_pcb, ModuleMid.kicad_pcb, Panel.kicad_pcb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]
2022-09-08 Software: - Added CV control, but for limited functions. - Added BPM mode.
    - Version ordered to Elecrow.
    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
    [ModuleBack.kicad_pcb, ModuleInterface.kicad_pcb, ModuleMid.kicad_pcb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]
2022-09-30 Added schematic pdf.
    [_module_back.sch, _module_interface.sch, _module_mid.sch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]
